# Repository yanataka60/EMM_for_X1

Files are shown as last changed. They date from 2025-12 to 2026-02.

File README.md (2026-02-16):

# EMMボード for X1

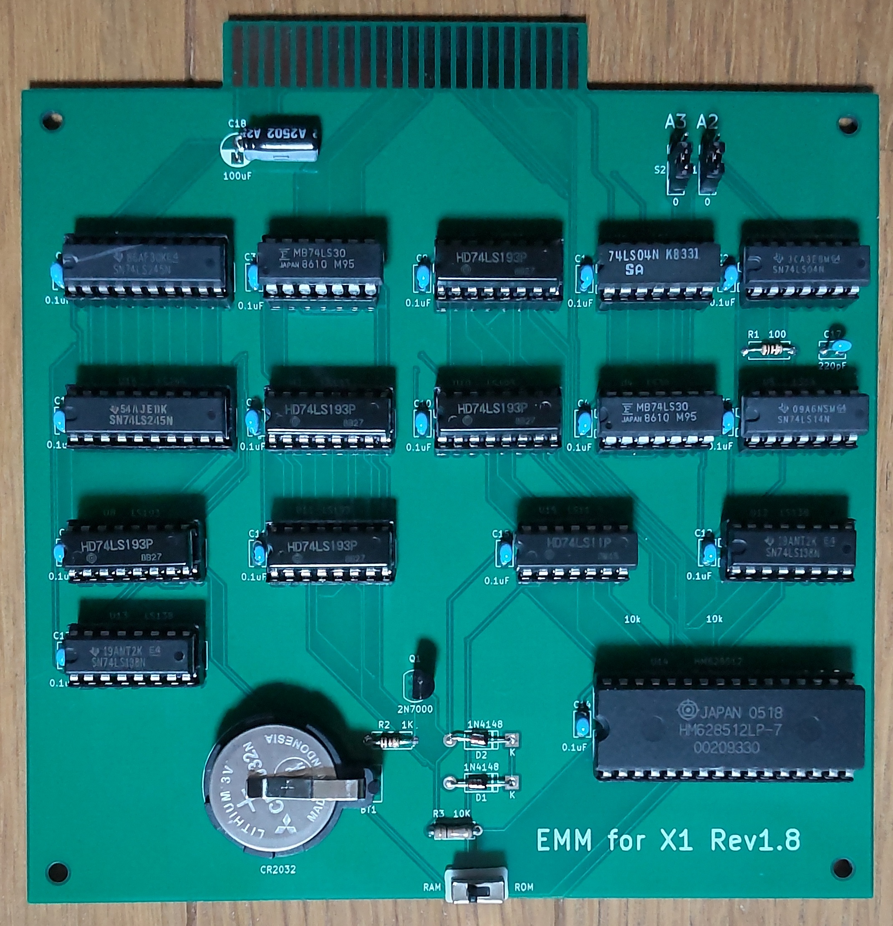
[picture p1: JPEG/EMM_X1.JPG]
TITLE


　X1、X1turbo用の512K S-RAM EMMボードを作ってみました。

　特徴としては、

　1)I/Oポートは、SHARP CZ-8EM互換なのでそのままCZ-8EM(320K EMM)として使えます。

　2)CR-2032のバックアップにより電源を切ってもメモリ内容が保持されます。(Rev1.8のバックアップ期間は計算上数年は大丈夫です。)

　3)スイッチにより書込み禁止にできます。

　4)I/Oポートから直接EMMを読み書きすれば512K外部RAMとして使えます。

　5)X1_SDと併用すれば512KまるごとSDカードからLOAD、SAVEが可能です。

　6)ジャンパによりEMM0～EMM3のいずれかに設定して使えます。

　7)おまけでアドレスカウンタリセットを付けました。

　なお、X1本体の通常の電源ON/OFFでの正常動作は確認していますが、電源ON/OFFを瞬間的に繰り返すような無理な使い方をするとEMMのバックアップが正常に動作しないことがあります。電源ON/OFFを瞬間的に繰り返すと電源ユニットにもダメージが及ぶこともあるので電源ON/OFFは間をおいて行ってください。

## 回路図

[回路図](https://github.com/yanataka60/EMM_for_X1/blob/main/Kicad/X1_EMM.pdf)
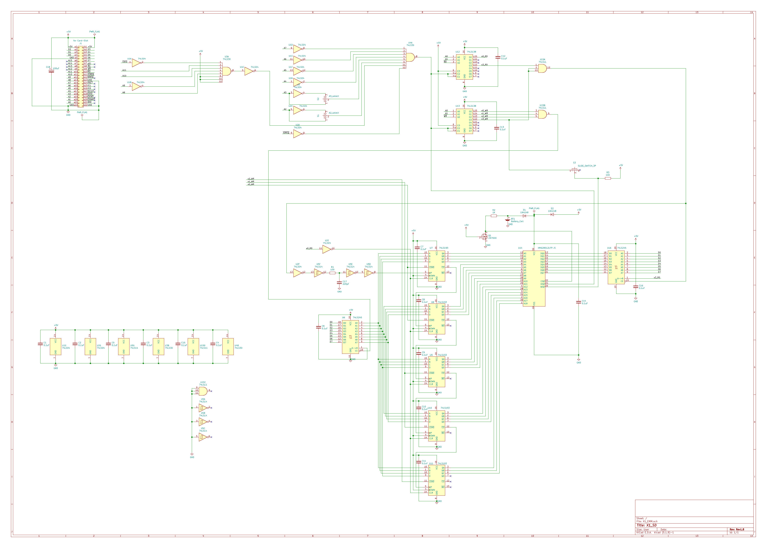
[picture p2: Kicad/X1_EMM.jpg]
回路図


## 部品表
|番号|品名|数量|備考|
| --- | --- | --- | --- |
|C1-C16,C19|積層セラミックコンデンサ 0.1uF|17||
|C17|積層セラミックコンデンサ 220pF|1||
|C18|電解コンデンサ 100uF|1||
|D1-D2|ダイオード 1N4148|2|1S4から1N4148に変更|
|Q1|FET 2N7000|1||
|R1|カーボン抵抗 100Ω|1||
|R2|カーボン抵抗 1k|1||
|R3|カーボン抵抗 10k|1||
|S1,S2|3Pスライドスイッチ又は1x3ピンヘッダとジャンパーピン|1|秋月電子通商 SS12D01G4又はPH-1X3SG,MJ-254-6BK等|
|S3|3Pスライドスイッチ|1|秋月電子通商 SS12D01G4等|
|U1,U2,U17|74LS04|3|樫木総業等|
|U3,U4|74LS30|2|樫木総業等|
|U5|74LS14|1|樫木総業等|
|U6,U16|74LS245|2|樫木総業等|
|U7-U11|74LS193|5|樫木総業等|
|U12,U13|74LS138|2|樫木総業等|
|U14|SRAM HM628512|1|注1)|
|U15|74LS11|1|樫木総業等|
|BT1|ボタン電池基板取付用ホルダー CR2032用(小型タイプ)|1|秋月電子通商 CH25-2032LFなど|

注1)DIPで設計しています。SOPを入手した場合にはこちらの変換基板を使うことで装着できます。

https://github.com/yanataka60/SOPtoDIP32

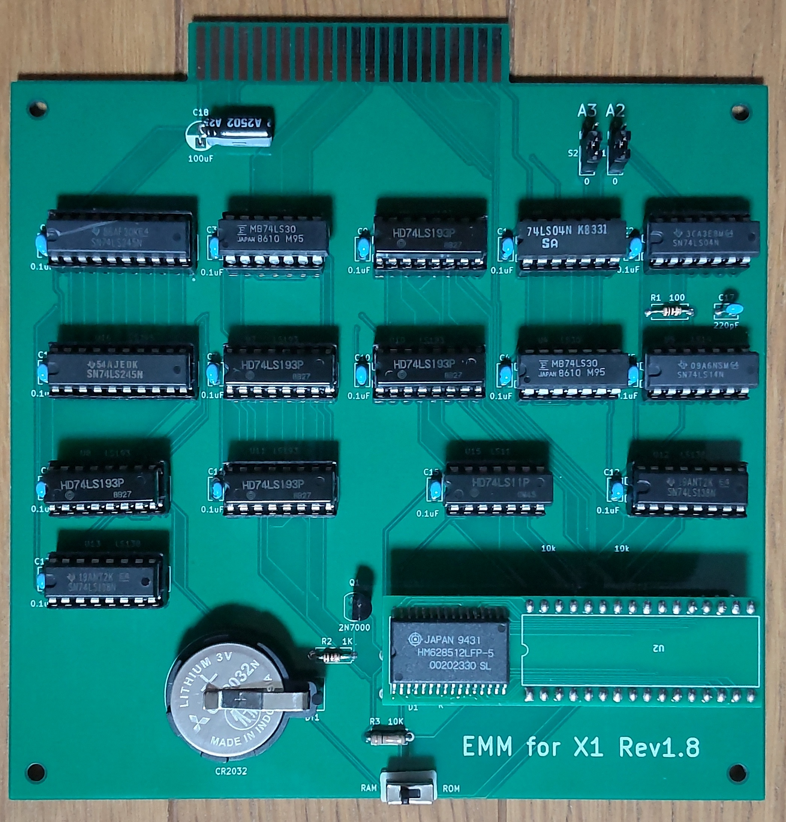
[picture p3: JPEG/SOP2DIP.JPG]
SOP2DIP


## I/Oポート
### EMM0
ジャンパピンA3、A2とも0の位置にします。

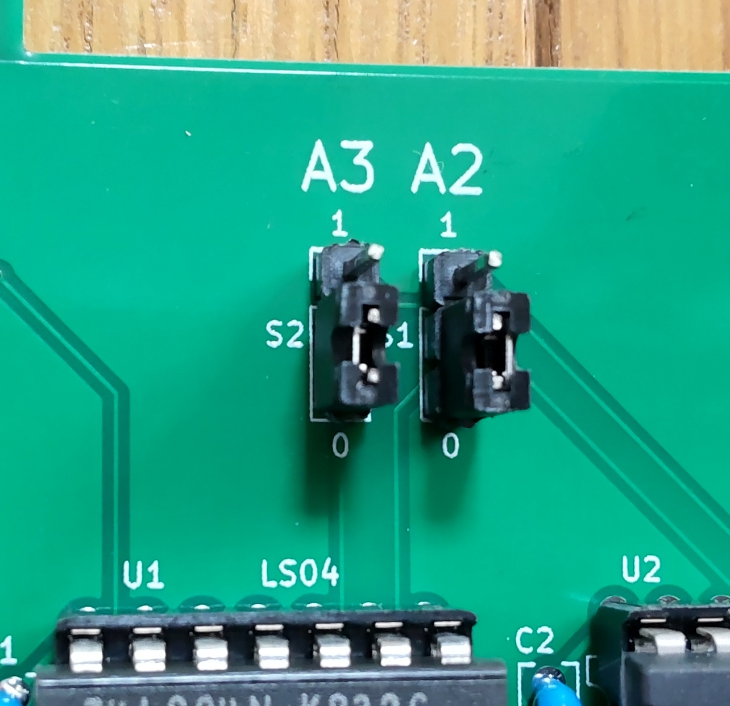
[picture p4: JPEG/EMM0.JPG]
EMM0


|アドレス|R/W|説明|
| --- | --- | --- |
|0D00h|R|アドレスカウンタリセット|
|0D00h|W|アドレスカウンタ Bit[7:0]|
|0D01h|W|アドレスカウンタ Bit[15:8]|
|0D02h|W|アドレスカウンタ Bit[18:16]|
|0D03h|R|データ読み出し:アドレスカウンタ+1|
|0D03h|W|データ書き込み:アドレスカウンタ+1|
### EMM1
ジャンパピンA3を0、A2を1の位置にします。

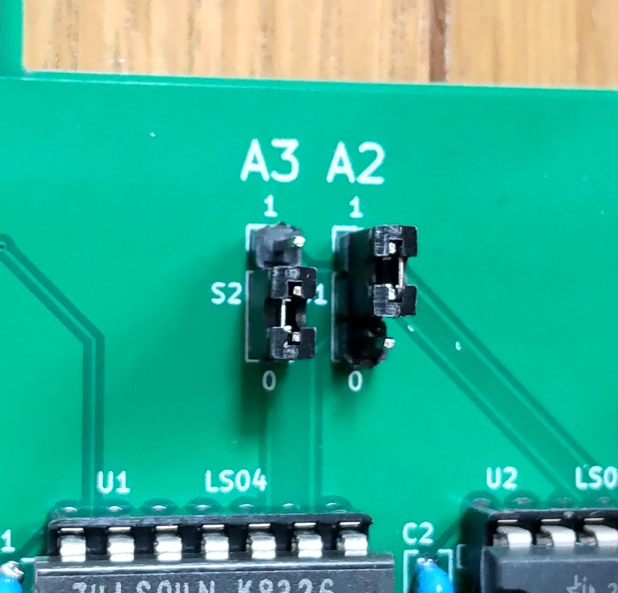
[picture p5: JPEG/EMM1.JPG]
EMM1


|アドレス|R/W|説明|
| --- | --- | --- |
|0D04h|R|アドレスカウンタリセット|
|0D04h|W|アドレスカウンタ Bit[7:0]|
|0D05h|W|アドレスカウンタ Bit[15:8]|
|0D06h|W|アドレスカウンタ Bit[18:16]|
|0D07h|R|データ読み出し:アドレスカウンタ+1|
|0D07h|W|データ書き込み:アドレスカウンタ+1|
### EMM2
ジャンパピンA3を1、A2を0の位置にします。

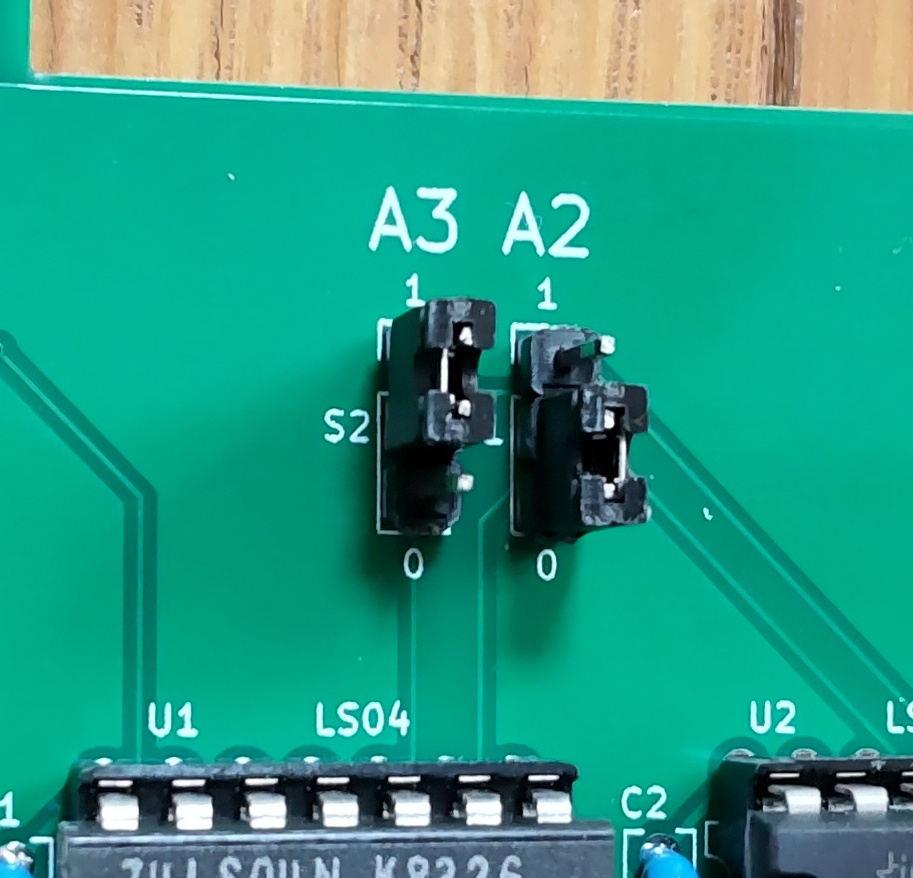
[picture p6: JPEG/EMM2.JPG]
EMM2


|アドレス|R/W|説明|
| --- | --- | --- |
|0D08h|R|アドレスカウンタリセット|
|0D08h|W|アドレスカウンタ Bit[7:0]|
|0D09h|W|アドレスカウンタ Bit[15:8]|
|0D0Ah|W|アドレスカウンタ Bit[18:16]|
|0D0Bh|R|データ読み出し:アドレスカウンタ+1|
|0D0Bh|W|データ書き込み:アドレスカウンタ+1|
### EMM3
ジャンパピンA3、A2とも1の位置にします。

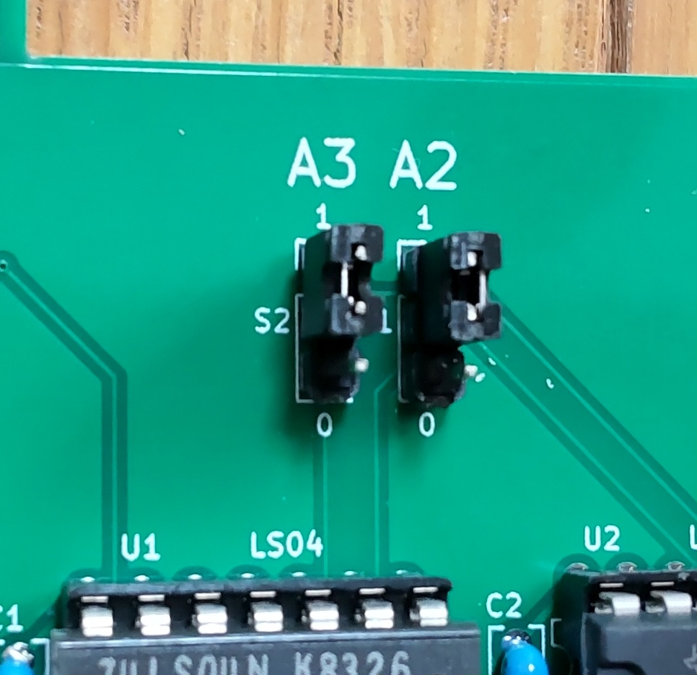
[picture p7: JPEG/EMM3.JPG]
EMM3


|アドレス|R/W|説明|
| --- | --- | --- |
|0D0Ch|R|アドレスカウンタリセット|
|0D0Ch|W|アドレスカウンタ Bit[7:0]|
|0D0Dh|W|アドレスカウンタ Bit[15:8]|
|0D0Eh|W|アドレスカウンタ Bit[18:16]|
|0D0Fh|R|データ読み出し:アドレスカウンタ+1|
|0D0Fh|W|データ書き込み:アドレスカウンタ+1|

## SAMPLEプログラム
　SAMPLEフォルダ内にEMMMENU、EMMCHECK、EMMTESTを置きました。

　使い方については、フォルダ内のREADME.mdを参照してください。

## EMMからの起動
　せっかくバッテリーバックアップに対応させたのでX1_SDの起動時にEMMから起動できるようにしてみました。

　X1_SDのROMをEMM対応BOOT LOADERに書き換える必要があります。

　X1_SDの「EMMボード for X1からの起動」を参照してください。

　https://github.com/yanataka60/X1_SD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

## 初期基板をバッテリーバックアップ対応とするには
#### 2026.2.16 Rev1.8基板ではバックアップ時間が飛躍的に増加し、ICに負荷をかけない回路となりました。バッテリーバックアップを使うなら出来ればRev1.8基板に更新してください。

　以下に示すパターンカット、ジャンパ、追加部品(74LS04×1個、抵抗10k×1本、ダイオード1S4×1本)で改造することで初期基板をバッテリーバックアップ対応とすることが可能です。

　部品を外すことなくパターンカットが可能ですが、ボード上に余っているゲートが無いため74LS04を1個追加しています。

### パターンカット個所
　HM628512の29PinとU15 74LS11 2Pinとの接続をカットします。

　HM628512の22、24Pin、R2 10Kとの接続点とU13 74LS138 5Pinとの接続をカットします。

　HM628512の22、24Pin、R2 10Kとの接続点とU12 74LS138 4Pinとの接続をカットします。

部品面全体
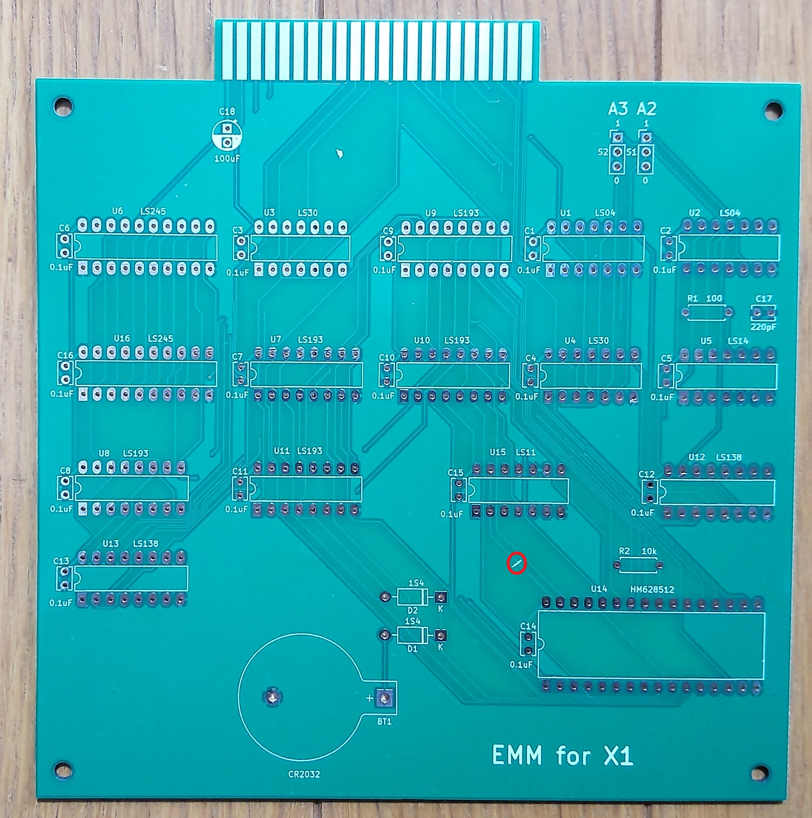
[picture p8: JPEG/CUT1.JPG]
cut1


ハンダ面全体
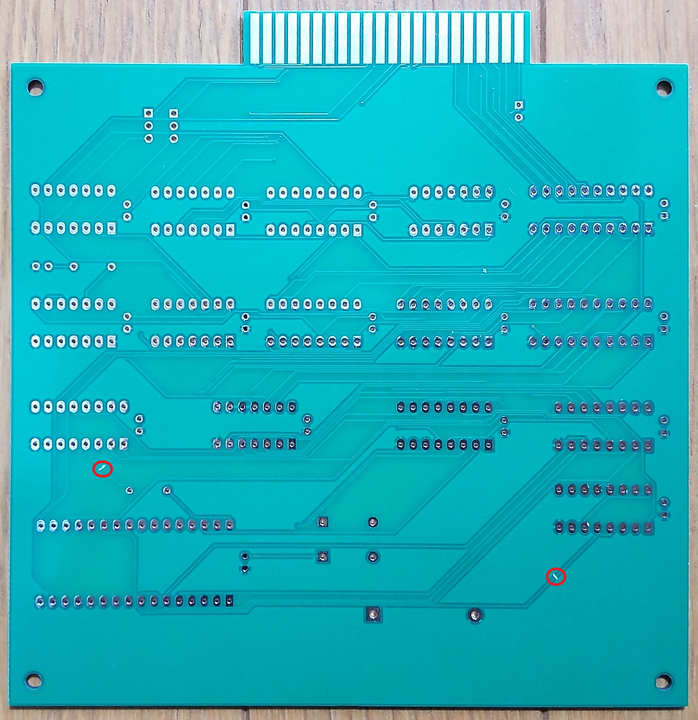
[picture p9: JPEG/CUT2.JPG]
cut2


### ジャンパ個所
　U12 74LS138 4PinとU13 74LS138 5Pin

　U13 74LS138 5Pinと追加74LS04 3Pin

　追加74LS04 4Pinと5Pin

　追加74LS04 6PinとU14 HM628512 24Pin(画像ではR2 10KのU14 HM628512 24Pinと接続されている方)

　U13 74LS138 12Pinと追加74LS04 11Pin

　追加74LS04 10Pinと9Pin

　追加74LS04 8Pinと追加ダイオード 1S4 アノード

　追加ダイオード 1S4 カソードとU14 HM628512 29Pin

　U14 HM628512 29Pinと追加抵抗 10KとU14 HM628512 32Pin

　U13 74LS138 8Pin(GND)と追加74LS04 7Pin(GND)

　U13 74LS138 16Pin(5V)と追加74LS04 14Pin(5V)

ハンダ面全体
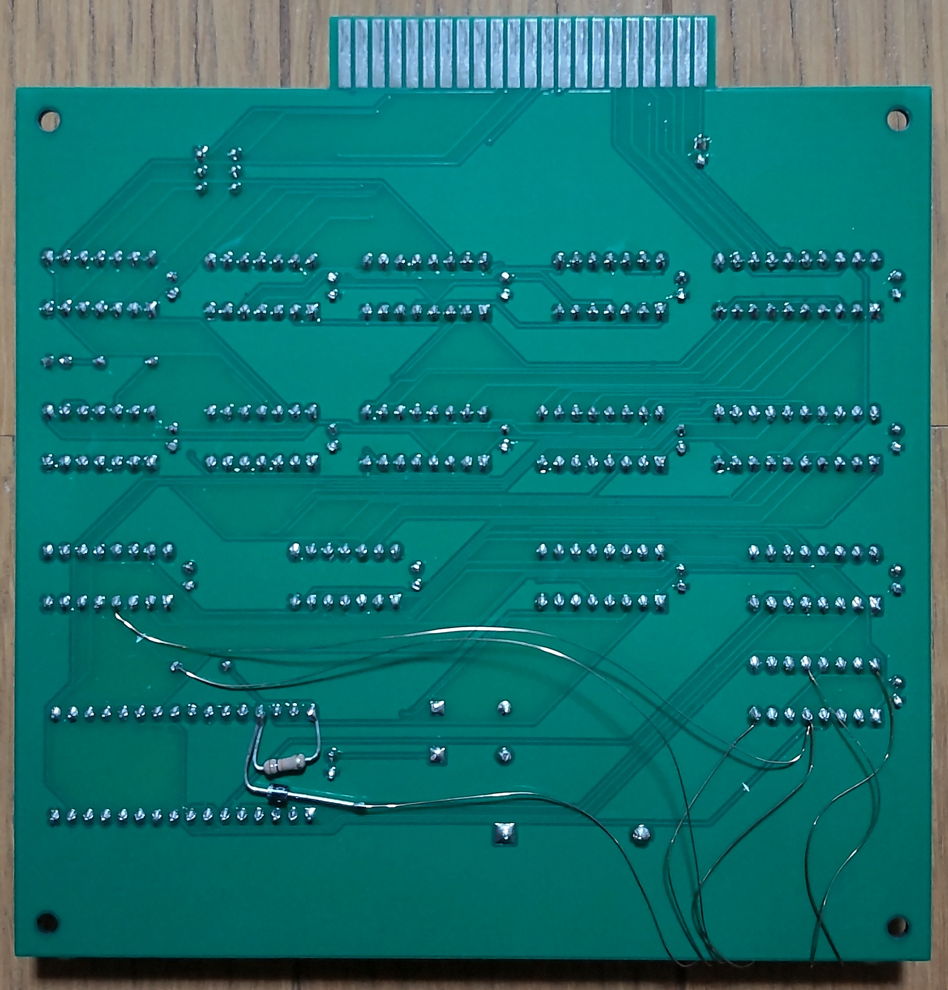
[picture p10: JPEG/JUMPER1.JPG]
jumper1


ハンダ面拡大1
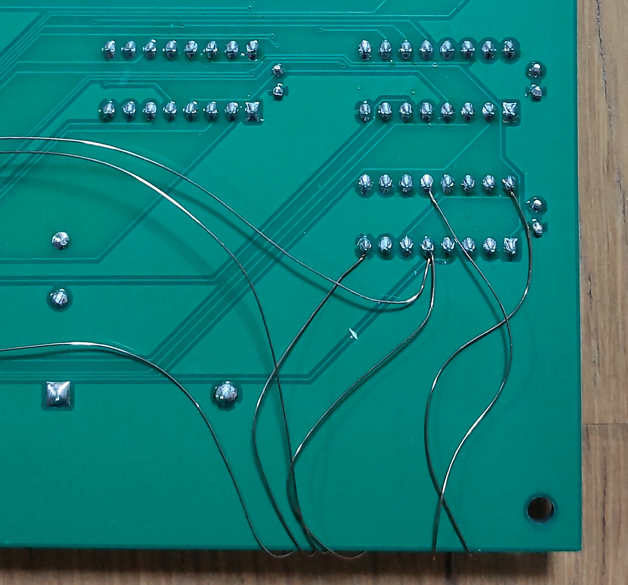
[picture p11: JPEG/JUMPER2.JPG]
jumper2


ハンダ面拡大2
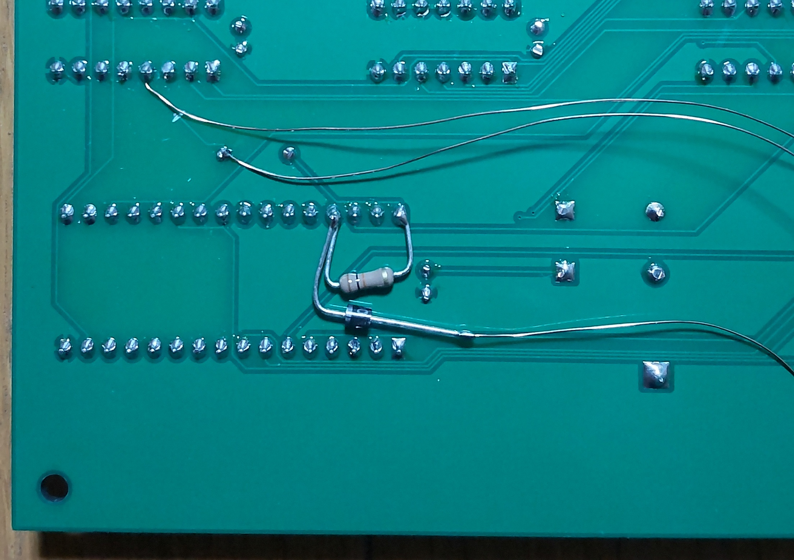
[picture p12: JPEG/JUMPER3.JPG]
jumper3


部品面全体
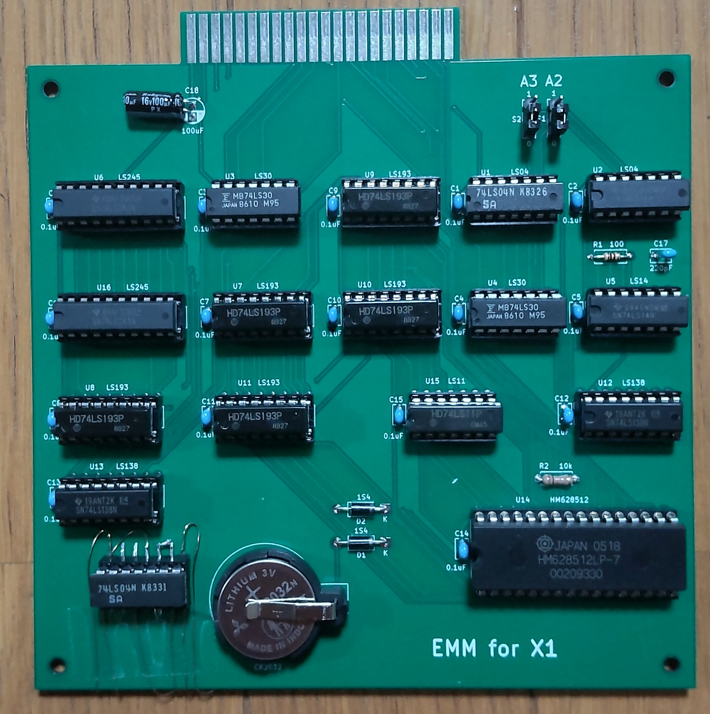
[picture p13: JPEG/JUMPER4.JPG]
jumper4


## 追記
2025.12.22 SAMPLEプログラムを追加しました。

2025.12.28 バッテリーバックアップしていてもメモリ内容が変わってしまう症状が時々発生しています。原因と対策を検討中です。

2026.1.1 簡単な修正では症状を抑えることが出来ないのでこのバージョンではバッテリーバックアップは断念し、対策を練りなおします。

2026.1.23 バッテリーバックアップ正常版(Rev1.5)に更新。初期基板をバッテリーバックアップ対応とするための改修方法を記述。

2026.1.23 バックアップ期間について追記。

2026.1.24 HM628512の書き込み時WE信号が瞬間的に5.9Vほどの電圧が掛かることを記述。すーぱーたーぼさんご指摘ありがとうございました。

2026.1.25 D1,D2を1S4から1N4148に変更。AIGOU Yoshiakiさんアドバイスありがとうございました。

2026.2.16 すーぱーたーぼさんに提案していただいていたn-FETを用いたバッテリーバックアップ回路を採用しました。すーぱーたーぼさんアドバイスありがとうございました。

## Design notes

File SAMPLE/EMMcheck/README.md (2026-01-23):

# EMMCHECK for X1_SD

　EMMボートの512K S-RAMの内容とX1_SDのファイルの内容を比較します。

　X1、X1turboで実行可能です。

　バッテリーバックアップが正常に機能しているかチェックするためのプログラムです。

## EMMCHECKの作成
　EMMCHECK.binを使いますが、BASIC CZ-8CB01から抜き出したIOCS(0000h～149Fh)が必要です。

　基本的にはX1_SDでの「ROMへの書込み」と同様です。

　まず、BASIC CZ-8CB01からIOCS(0000h～149Fh)を抜き出し、バイナリファイルとして保存します。

　CZ-8FB01 V10、CZ-8FB01 V20も大丈夫だとは思いますが、検証していません。なお、X1turbo用BASICは使えません。

　　DumpList Editorを使ってBASIC CZ-8CB01のWav又はtapファイルを読み込み、「マシン語入力に送る」を実行します。

　　マシン語の14A0h以降を削除します。(0000h～149Fhのマシン語にします)

　　「ファイル書出し」の「BIN(mot)ファイル書き出し(ヘッダ無し)(for他汎用)」を選択して「IOCS.bin」という名前で保存します。

　保存した「IOCS.bin」の後ろにバイナリエディタ等を使って「EMMCHECK.bin」を付け加えます。0000h～19B5hのファイルとなるはずです。

　次にファイルの先頭に以下に示す32Byteのヘッダを付加します。0000h～19D5hのファイルとなります。

　[0000] 01 45 4D 4D 43 48 45 43 4B 20 20 20 20 20 20 20

　[0010] 20 20 B5 19 00 00 00 00 20 20 20 20 20 20 00 00

　出来上がったら「EMMCHECK.X1T」という名前で保存します。

## EMMCHECKの使い方
　起動するとまず対象とするEMMをEMM0～EMM3の中から数字で選択します。

　次に比較するファイルを指定します。

　「FNAME:」と聞いてきますので次のうちから選択して入力します。

### [BREAK]キー
　処理が中断されたものとしてMONITOR入力待ちに戻ります。

### DOSファイル名を入力せずそのまま[CR]キー
　選択したEMMに対応するEMMx.X1T(EMM0.X1T、EMM1.X1T、EMM2.X1T、EMM3.X1T)をDOSファイル名として比較します。

### DOSファイル名を入力して[CR]キー
　入力されたDOSファイル名のファイルと比較とします。拡張子の「X1T」は省略可能です。

### *F xxx[CR]キー
　SDカードに保存されている文字列xxxから始まるDOSファイル名を一覧表示します。xxxを省略した場合はすべてのファイルが一覧表示対象となります。

　20件表示したところで指示待ちになるので打ち切るならSHIFT+BREAK又は↑を入力すると打ち切られ、Bキーで前の20件に戻ります。それ以外のキーで次の20件を表示します。

　検索結果の行頭には「FNAME:」を付加して表示してあるので比較したいファイルにカーソルキーを合わせて[CR]キーを押すだけで選択が可能です。

例)

FNAME:[CR]

FNAME:EMM0-TEST[CR]

FNAME:*F EMM[CR]

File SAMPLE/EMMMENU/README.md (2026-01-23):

# EMMMENU(SDからEMMへLOAD、EMMからSDへSAVE) for X1_SD

X1_SDを使い、EMMボートの512K S-RAMの内容をまるごとSDへSAVE、またSDにSAVEされたEMMの内容をまるごとEMMボートへLOADするプログラムです。

X1、X1turboで実行可能です。

EMMSAVEでSDカードに保存されるEMM DUMPファイルはX1Tファイルのヘッダが付加され512KB+32Byte=524320Byteになります。

なお、EMM DUMPファイルはWindowsパソコンのエミュレーター2種類で利用可能であることを確認しています。

## 利用可能なエミュレーター

### TAKEDAさんのeX1, eX1twin, eX1turbo, eX1turboZ

https://takeda-toshiya.my.coocan.jp/

　EMM DUMPファイルから32Byteのヘッダを除去し、EMM.BINにリネームしてエミュレーターと同じフォルダに置けばエミュレーターから利用できるようになります。

　eX1, eX1twin, eX1turbo, eX1turboZは、16MのEMM0として対応しているようです。EMM DUMPファイルから32Byteのヘッダを除去した524288Byte、327680Byte(Hu-BASICから認識可能分)のEMM.BINでも問題なく認識しますが、エミュレーターを終了させると16MByteのファイルとして再作成されます。

　16MByteとして作成されたEMM.BINに32Byteのヘッダをつけて拡張子をX1TとすればEMM DUMPファイルとしてEMMLOADが可能です。(LOADされるのは先頭512kByte分のみ)

　この時、付加する32Byteのヘッダの内容はどんな内容でも構わないので00hを32Byte等好きにつけてください。

### X millennium T-tune系
　色々なバージョンが存在する中でEMMに対応しているのはT-tune系だけのようです。

　YATYATYATさんのX Millennum 106CT Ver 0.26 t-tune 1.68

　https://xmil106.web.fc2.com/toppage.html

　X1センター様のX Millennum Ver 0.26 t-tune step 1.43

　http://www.x1center.org/

　EMM DUMPファイルから32Byteのヘッダを除去し、EMMx.MEM(EMM0.MEM、EMM1.MEM、EMM2.MEM、EMM3.MEM)にリネームしてエミュレーターと同じフォルダに置けばエミュレーターから利用できるようになります。

　320KB EMMしかサポートしていない気がしますが、エミュレーター終了時に書き出されるときにファイルサイズは変化しないようです。

　EMMx.MEM(EMM0.MEM、EMM1.MEM、EMM2.MEM、EMM3.MEM)に32Byteのヘッダをつけて拡張子をX1TとすればEMM DUMPファイルとしてEMMLOADが可能です。ファイル長が320KB+32BytのときもEMMLOADにそのまま使えます。

　付加する32Byteのヘッダの内容はどんな内容でも構わないので00hを32Byte等好きにつけてください。

## EMMMENUの作成
　EMMMENU.binを使いますが、BASIC CZ-8CB01から抜き出したIOCS(0000h～149Fh)が必要です。

　基本的にはX1_SDでの「ROMへの書込み」と同様です。

　まず、BASIC CZ-8CB01からIOCS(0000h～149Fh)を抜き出し、バイナリファイルとして保存します。

　CZ-8FB01 V10、CZ-8FB01 V20も大丈夫だとは思いますが、検証していません。なお、X1turbo用BASICは使えません。

　　DumpList Editorを使ってBASIC CZ-8CB01のWav又はtapファイルを読み込み、「マシン語入力に送る」を実行します。

　　マシン語の14A0h以降を削除します。(0000h～149Fhのマシン語にします)

　　「ファイル書出し」の「BIN(mot)ファイル書き出し(ヘッダ無し)(for他汎用)」を選択して「IOCS.bin」という名前で保存します。

　保存した「IOCS.bin」の後ろにバイナリエディタ等を使って「EMMMENU.bin」を付け加えます。0000h～1AD6hのファイルとなるはずです。

　次にファイルの先頭に以下に示す32Byteのヘッダを付加します。0000h～1AF6hのファイルとなります。

　[0000] 01 45 4D 4D 4D 45 4E 55 20 20 20 20 20 20 20 20

　[0010] 20 20 D6 1A 00 00 00 00 20 20 20 20 20 20 00 00

　出来上がったら「EMMMENU.X1T」という名前で保存します。

## EMMMENUの使い方
　起動するとまず対象とするEMMをEMM0～EMM3の中から数字で選択します。

　次にEMMLOAD、EMMSAVE、EXITを数字で選択します。

　EXIT及びEMMLOAD、EMMSAVE終了時に別のプログラムを実行したいときはIPLリセットしてください。

### 1)EMMLOAD
　選択すると「FNAME:」と聞いてきますので次のうちから選択して入力します。

#### [BREAK]キー
　処理が中断されたものとしてEXIT処理になります。

#### DOSファイル名を入力せずそのまま[CR]キー
　選択したEMMに対応するEMMx.X1T(EMM0.X1T、EMM1.X1T、EMM2.X1T、EMM3.X1T)をDOSファイル名としてSDカードから選択したEMMに転送します。

#### DOSファイル名を入力して[CR]キー
　入力されたDOSファイル名のファイルをSDカードから選択したEMMに転送します。拡張子の「X1T」は省略可能です。

#### *F xxx[CR]キー
　SDカードに保存されている文字列xxxから始まるDOSファイル名を一覧表示します。xxxを省略した場合はすべてのファイルが一覧表示対象となります。

　20件表示したところで指示待ちになるので打ち切るならSHIFT+BREAK又は↑を入力すると打ち切られ、Bキーで前の20件に戻ります。それ以外のキーで次の20件を表示します。

　検索結果の行頭には「FNAME:」を付加して表示してあるのでLOADしたいファイルにカーソルキーを合わせて[CR]キーを押すだけでLOADが可能です。

　SDからEMMへの転送にかかる時間は約120秒です。

例)

FNAME:[CR]

FNAME:EMM0-TEST[CR]

FNAME:*F EMM[CR]

### 2)EMMSAVE
　選択すると先に選択していたEMMによりEMMx-SAVE.X1T(EMM0-SAVE.X1T、EMM1-SAVE.X1T、EMM2-SAVE.X1T、EMM3-SAVE.X1T)というファイルがSDカードに作成されます。

　同名のファイルがあると上書きされます。SDに保存されるファイル名はEMMx-SAVE.X1T(EMM0-SAVE.X1T、EMM1-SAVE.X1T、EMM2-SAVE.X1T、EMM3-SAVE.X1T)に固定されていて指定はできません。

　EMMからSDへの保存にかかる時間は約150秒です。

### 追記
　MZ-2000_SD用のEMMSAVEで時々失敗することがあり、失敗するとMZ-2000_SDからSDカードにアクセス不可能になってしまう事象が発生します。

　こちらのX1用EMMSAVEでは今のところ発生していませんが、もし発生した場合の復旧方法は以下の通りです。なお、SDカードに多くのファイルが登録されていると発生する可能性が高い気がします。

　EMMSAVEを実行するときは必要最小限のファイル(X1_SD_BOOT.X1T、EMMMENU.X1T)だけが登録された専用のSDカードで実行でしてみてください。

　X1_SDからアクセス不可能になったSDカードもWindowsからは問題なくアクセスできるのでSDカードから作成に失敗したEMMx-SAVE.X1Tを削除したのちにすべての内容を一旦Windowsのフォルダに移動させ、SDカードにファイルが一つもない状態にしてから退避したWindowsのフォルダからすべてのファイルを戻すことで復旧できます。

--------------------------------------------------------------------------------------------------

2025.12.22 X millennium系のエミュレーターの中でEMMをサポートしているのはT-tune系であることを追記。

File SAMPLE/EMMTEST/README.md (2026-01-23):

# EMMTEST

　EMMボートの512K S-RAMの読み書きテストプログラムです。

　X1、X1turboで実行可能です。

　RAMの内容を一時退避しながらテストしますのでRAMの読み書きが正常であればEMMの内容が変化してしまうことはありません。

## EMMTESTの作成
　EMMTEST.binを使いますが、BASIC CZ-8CB01から抜き出したIOCS(0000h～149Fh)が必要です。

　基本的にはX1_SDでの「ROMへの書込み」と同様です。

　まず、BASIC CZ-8CB01からIOCS(0000h～149Fh)を抜き出し、バイナリファイルとして保存します。

　CZ-8FB01 V10、CZ-8FB01 V20も大丈夫だとは思いますが、検証していません。なお、X1turbo用BASICは使えません。

　　DumpList Editorを使ってBASIC CZ-8CB01のWav又はtapファイルを読み込み、「マシン語入力に送る」を実行します。

　　マシン語の14A0h以降を削除します。(0000h～149Fhのマシン語にします)

　　「ファイル書出し」の「BIN(mot)ファイル書き出し(ヘッダ無し)(for他汎用)」を選択して「IOCS.bin」という名前で保存します。

　保存した「IOCS.bin」の後ろにバイナリエディタ等を使って「EMMTEST.bin」を付け加えます。0000h～1665hのファイルとなるはずです。

　次にファイルの先頭に以下に示す32Byteのヘッダを付加します。0000h～1685hのファイルとなります。

　[0000] 01 45 4D 4D 54 45 53 54 20 20 20 20 20 20 20 20

　[0010] 20 20 65 16 00 00 00 00 20 20 20 20 20 20 00 00

　出来上がったら「EMMTEST.X1T」という名前で保存します。

## EMMTESTの使い方
　起動すると対象とするEMMをEMM0～EMM3の中から数字で選択するとテストが始まります。(00000h～7FFFFh)

　書き込んだ内容が正常に読み出せない場合にはエラーと表示して停止します。

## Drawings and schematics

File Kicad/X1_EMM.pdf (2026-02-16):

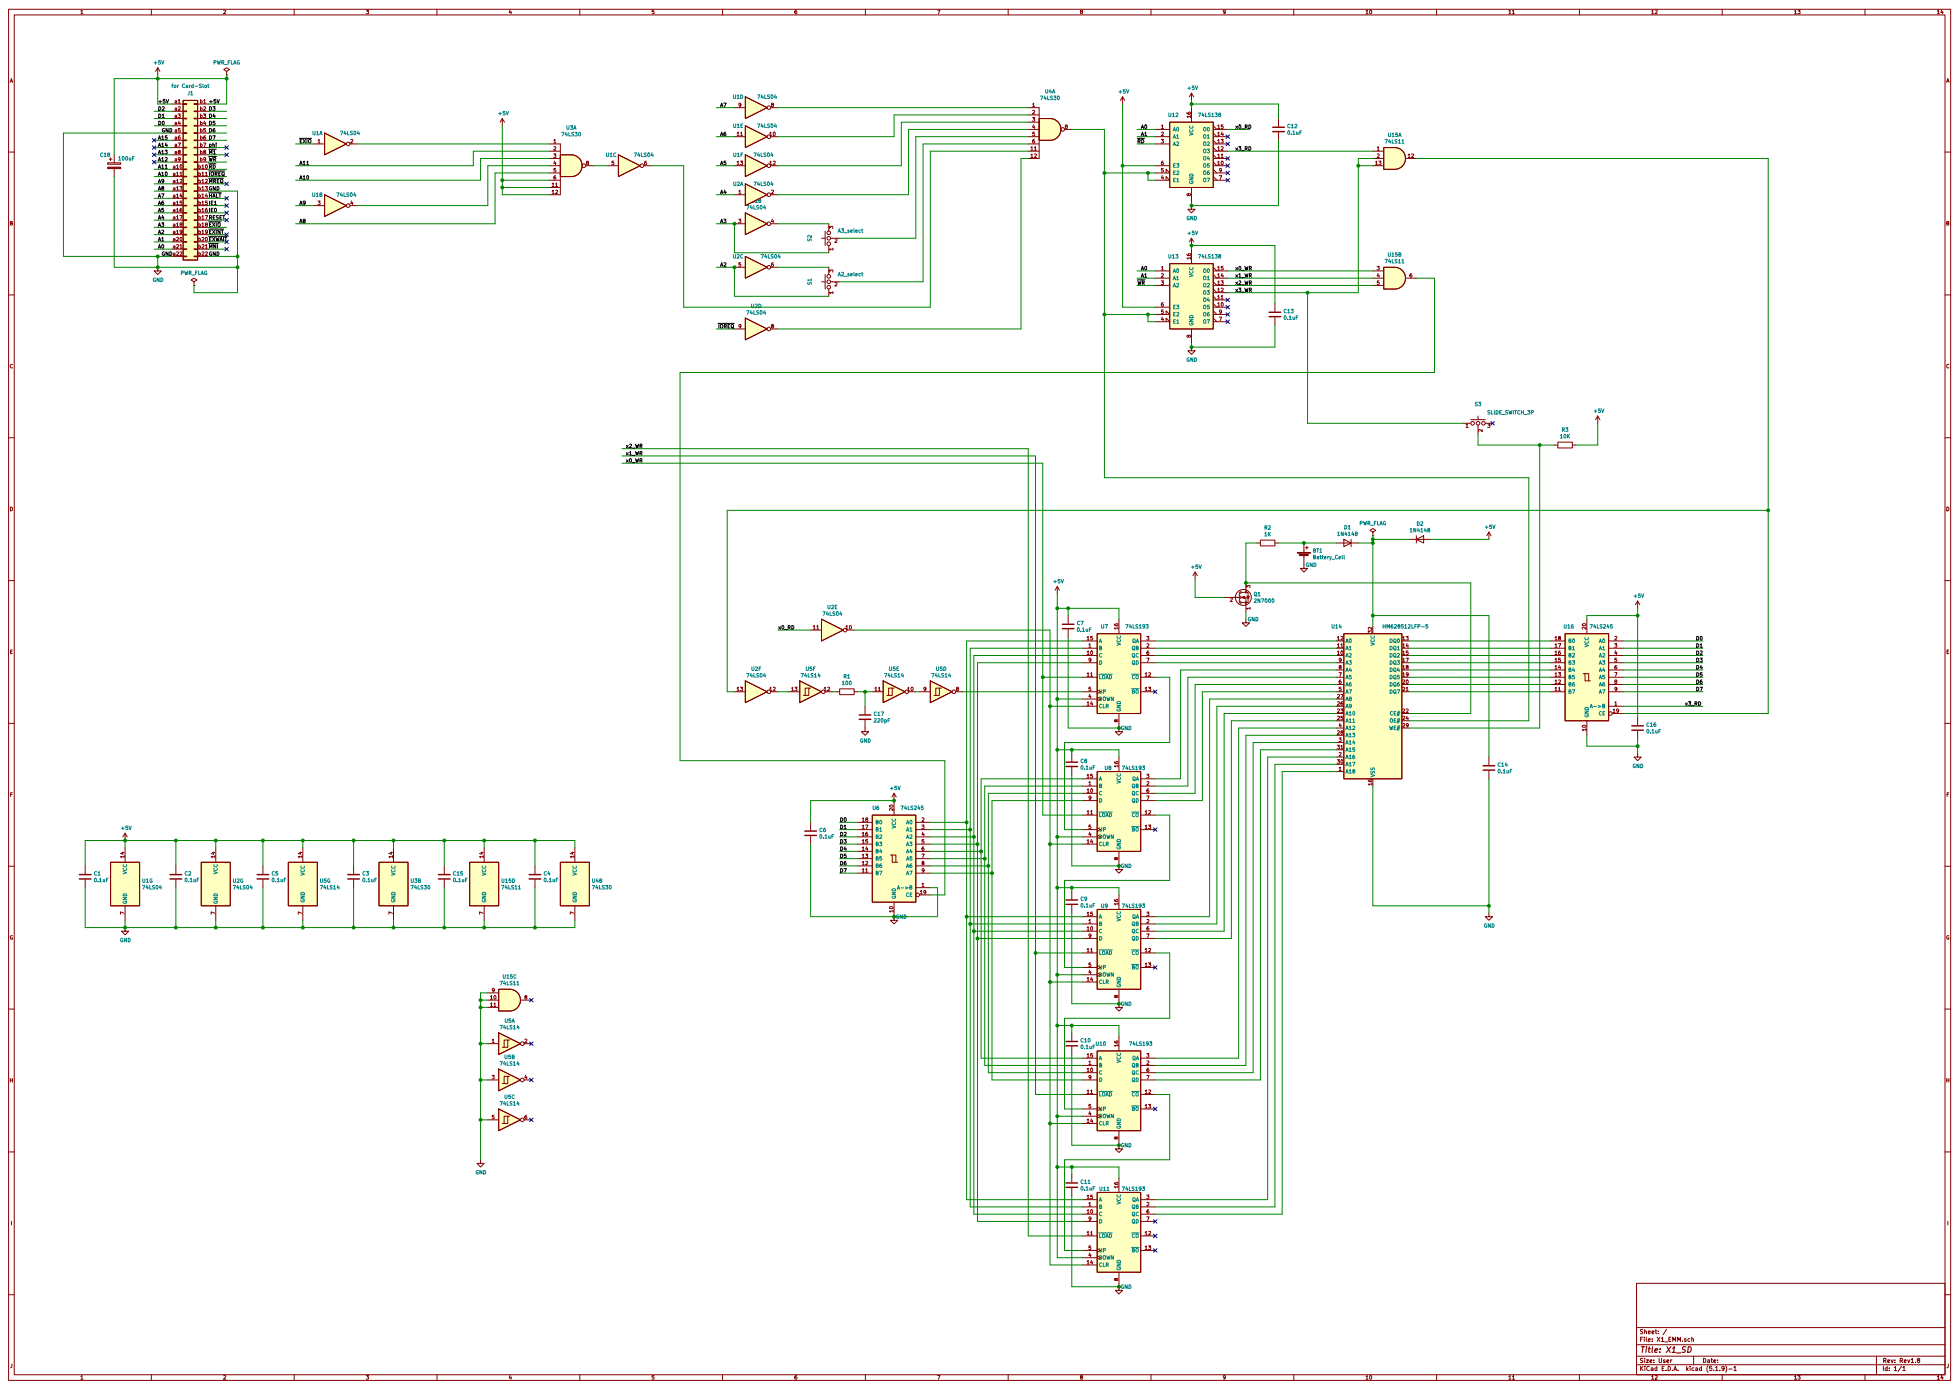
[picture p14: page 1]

14 O0 x1_WR
13 O1 x2_WR
12 O2 x3_WR
11 O3 10 O4

20 DQ7
21 CE# | x3_RD

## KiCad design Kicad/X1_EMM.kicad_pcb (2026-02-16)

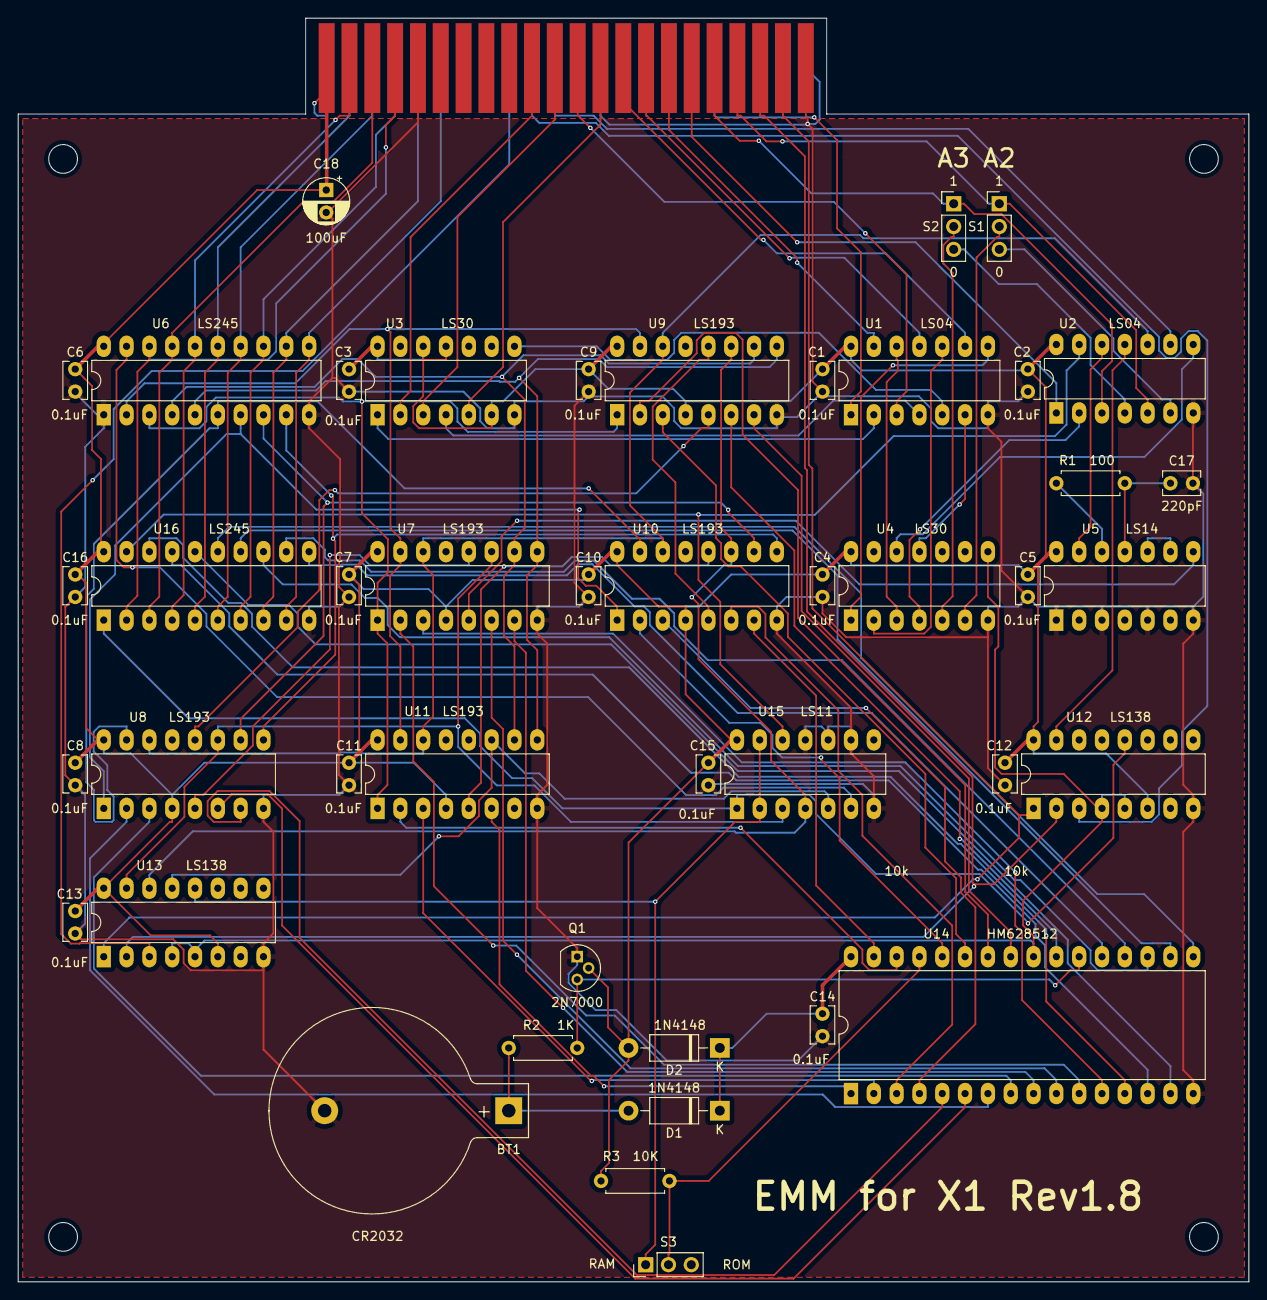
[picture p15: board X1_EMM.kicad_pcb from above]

Board: 2 copper layers, 137.0 x 140.7 mm, 49 parts (0 on the bottom side), 97 nets.

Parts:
BT1: Battery_Cell; BatteryHolder_Keystone_103_1x20mm
C1, C2, C3, C4, C5, C6, C7, C8, C9, C10, C11, C12, C13, C14, C15, C16: 0.1uF; C_Rect_L4.0mm_W2.5mm_P2.50mm
C17: 220pF; C_Rect_L4.0mm_W2.5mm_P2.50mm
C18: 100uF; CP_Radial_D5.0mm_P2.50mm
D1, D2: 1N4148; D_DO-41_SOD81_P10.16mm_Horizontal
J1: for Card-Slot; BUS_MZ2000
MH1, MH2, MH3, MH4: MountingHole_3.2mm_M3
Q1: 2N7000; TO-92
R1: 100; R_Axial_DIN0207_L6.3mm_D2.5mm_P7.62mm_Horizontal
R2: 1K; R_Axial_DIN0207_L6.3mm_D2.5mm_P7.62mm_Horizontal
R3: 10K; R_Axial_DIN0207_L6.3mm_D2.5mm_P7.62mm_Horizontal
S1: A2_select; PinHeader_1x03_P2.54mm_Vertical
S2: A3_select; PinHeader_1x03_P2.54mm_Vertical
S3: SLIDE_SWITCH_3P; PinHeader_1x03_P2.54mm_Vertical
U1, U2: 74LS04; DIP-14_W7.62mm_LongPads
U3, U4: 74LS30; DIP-14_W7.62mm_LongPads
U5: 74LS14; DIP-14_W7.62mm_LongPads
U6, U16: 74LS245; DIP-20_W7.62mm_LongPads
U7, U8, U9, U10, U11: 74LS193; DIP-16_W7.62mm_LongPads
U12, U13: 74LS138; DIP-16_W7.62mm_LongPads
U14: HM628512LFP-5; DIP-32_W15.24mm_LongPads
U15: 74LS11; DIP-14_W7.62mm_LongPads

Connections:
+5V: C1.1, C2.1, C3.1, C4.1, C5.1, C6.1, C7.1, C8.1, C9.1, C10.1, C11.1, C12.1, C13.1, C15.1, C16.1, C18.1, D2.2, J1.a1, J1.b1, Q1.2, R3.2, U1.14, U2.14, U3.6, U3.11, U3.12, U3.14, U4.14, U5.14, U6.20, U7.4, U7.16, U8.4, U8.16, U9.4, U9.16, U10.4, U10.16, U11.4, U11.16, U12.6, U12.16, U13.6, U13.16, U15.14, U16.20
/A0: J1.a21, U12.1, U13.1
/A1: J1.a20, U12.2, U13.2
/A2: J1.a19, S1.1, U2.5
/A3: J1.a18, S2.1, U2.3
/A4: J1.a17, U2.1
/A5: J1.a16, U1.13
/A6: J1.a15, U1.11
/A7: J1.a14, U1.9
/A8: J1.a13, U3.5
/A9: J1.a12, U1.3
/A10: J1.a11, U3.3
/A11: J1.a10, U3.2
/D0: J1.a4, U6.18, U16.2
/D1: J1.a3, U6.17, U16.3
/D2: J1.a2, U6.16, U16.4
/D3: J1.b2, U6.15, U16.5
/D4: J1.b3, U6.14, U16.6
/D5: J1.b4, U6.13, U16.7
/D6: J1.b5, U6.12, U16.8
/D7: J1.b6, U6.11, U16.9
/x0_RD: U2.11, U12.15
/x0_WR: U7.11, U8.11, U13.15, U15.3
/x1_WR: U9.11, U10.11, U13.14, U15.4
/x2_WR: U11.11, U13.13, U15.5
/x3_RD: U12.12, U15.1, U16.1
/x3_WR: S3.1, U13.12, U15.2, U15.13
/~EXIO: J1.b18, U1.1
/~IOREQ: J1.b11, U2.9
/~RD: J1.b10, U12.3
/~WR: J1.b9, U13.3
GND: BT1.2, C1.2, C2.2, C3.2, C4.2, C5.2, C6.2, C7.2, C8.2, C9.2, C10.2, C11.2, C12.2, C13.2, C14.2, C15.2, C16.2, C17.2, C18.2, J1.a5, J1.a22, J1.b13, J1.b22, Q1.1, U1.7, U2.7, U3.7, U4.7, U5.1, U5.3, U5.5, U5.7, U6.1, U6.10, U7.8, U8.8, U9.8, U10.8, U11.8, U12.8, U13.8, U14.16, U15.7, U15.9, U15.10, U15.11, U16.10
unnamed: BT1.1, D1.2, R2.2
unnamed: C14.1, D1.1, D2.1, U14.32
unnamed: C17.1, R1.2, U5.11
unnamed: Q1.3, R2.1, U14.22
unnamed: R1.1, U5.12
unnamed: R3.1, S3.2, U14.29
unnamed: S1.2, U4.6
unnamed: S1.3, U2.6
unnamed: S2.2, U4.5
unnamed: S2.3, U2.4
unnamed: U1.2, U3.1
unnamed: U1.4, U3.4
unnamed: U1.5, U3.8
unnamed: U1.6, U4.11
unnamed: U1.8, U4.1
unnamed: U1.10, U4.2
unnamed: U1.12, U4.3
unnamed: U2.2, U4.4
unnamed: U2.8, U4.12
unnamed: U2.12, U5.13
unnamed: U5.8, U7.5
unnamed: U5.9, U5.10
unnamed: U7.12, U8.5
unnamed: U8.12, U9.5
unnamed: U6.7, U8.1, U10.1
unnamed: U10.2, U14.28
unnamed: U10.3, U14.4
unnamed: U9.12, U10.5
unnamed: U10.6, U14.3
unnamed: U10.7, U14.31
unnamed: U6.9, U8.9, U10.9
unnamed: U6.8, U8.10, U10.10
unnamed: U10.12, U11.5
unnamed: U2.10, U7.14, U8.14, U9.14, U10.14, U11.14
unnamed: U6.6, U8.15, U10.15
unnamed: U6.3, U7.1, U9.1, U11.1
unnamed: U11.2, U14.30
unnamed: U11.3, U14.2
unnamed: U11.6, U14.1
unnamed: U6.5, U7.9, U9.9, U11.9
unnamed: U6.4, U7.10, U9.10, U11.10
unnamed: U6.2, U7.15, U9.15, U11.15
unnamed: U4.8, U12.4, U12.5, U13.4, U13.5, U14.24
unnamed: U8.7, U14.5
unnamed: U8.6, U14.6
unnamed: U8.2, U14.7
unnamed: U8.3, U14.8
unnamed: U7.7, U14.9
unnamed: U7.6, U14.10
unnamed: U7.2, U14.11
unnamed: U7.3, U14.12
unnamed: U14.13, U16.18
unnamed: U14.14, U16.17
unnamed: U14.15, U16.16
unnamed: U14.17, U16.15
unnamed: U14.18, U16.14
unnamed: U14.19, U16.13
unnamed: U14.20, U16.12
unnamed: U14.21, U16.11
unnamed: U9.6, U14.23
unnamed: U9.7, U14.25
unnamed: U9.2, U14.26
unnamed: U9.3, U14.27
unnamed: U6.19, U15.6
unnamed: U2.13, U15.12, U16.19
